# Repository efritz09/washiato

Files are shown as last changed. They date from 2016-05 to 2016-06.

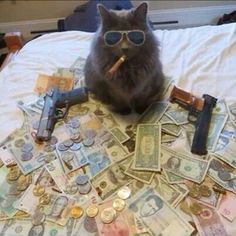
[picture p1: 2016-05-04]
Cat pictures/Thug_Kitty2.jpg

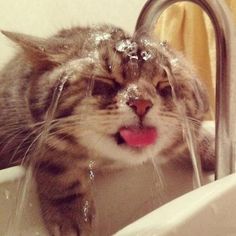
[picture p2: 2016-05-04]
Cat pictures/Idiot_Cat.jpg

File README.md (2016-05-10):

# washiato
ME 202 project

- Arya Banait
- Denny Delp
- Eric Fritz
- Tom the Tank Engine

=================
Have you ever started your laundry only to remember hours later that you never moved it over to the dryer?

Have you ever gone to pick up your laundry and some jerk has already moved it?

Enter **washiato**, a disruptive cloud based laundry monitoring system that will revolutionize the way you experience laundry!

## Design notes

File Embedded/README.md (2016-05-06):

# washiato
ME 202 project

### Installing the wifi board
To upload code to the huzzah board, follow the instructions here: [https://github.com/esp8266/Arduino](https://github.com/esp8266/Arduino)

#### Notes:
We're currently using a rolling mean and standard deviation to determine movement, using the algorithm defined here: [http://jonisalonen.com/2014/efficient-and-accurate-rolling-standard-deviation/](http://jonisalonen.com/2014/efficient-and-accurate-rolling-standard-deviation/)

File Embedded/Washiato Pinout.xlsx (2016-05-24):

Washiato Pinout
HUZZAH Pin | Connected To
0 | LCD RS
2 | LCD E
4 | Accelerometer SDA
5 | Accelerometer SCL
12 | LCD D4
13 | LCD D5
14 | LCD D6
15 | 2N7000 Gate
16 | LCD D7
3V | Accelerometer 3.3V
VBAT | 5 V supply
LCD Pin | Connected To
VSS | GND
VDD | 5V
V0 | Pot wiper
RS | Huzzah 0
RW | GND
E | HUZZAH 2
D0
D1
D2
D3
D4 | HUZZAH 12
D5 | HUZZAH 13
D6 | HUZZAH 14
D7 | HUZZAH 16
A | 5V
K | 2N7000 Drain

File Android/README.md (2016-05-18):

# washiato
ME 202 project

### Ideas for libraries
Since Adriano says we need to use 2 more libraries, here's a short list of some that I think we could use:

[Leak Canary](https://github.com/square/leakcanary): Detects memory leaks and stops them.

[Calligraphy](https://github.com/chrisjenx/Calligraphy): Custom fonts.

Otherwise, check out [this](https://github.com/codepath/android_guides/wiki/Must-Have-Libraries) for more libraries. There's a huge list that's split up into categories at the bottom.

=================================================================================================
### 05/17/2016- Arya
Current status: Major OMW and logout bugs are fixed. Guest logout fixed. 

Everything operates under the assumption that the user does not log out during a washing cycle. 
If they do so, we "lose" the pairing with NFC serial (its exists in Firebase, but is not displayed if they log back in). 
This is a small enough bug and I think we are okay for checkoff; but we should try to fix it for later!

Next Steps: Fix this bug such that an NFC serial stays associated with a user until the cycle is finished for them 
(and also display that even if they log out and log back in during a cycle).

=================================================================================================
### 05/16/2016- Arya
Control Activity page displays current and default cluster for each user (so does FireBase). 
I was trying to get Cluster Activity to display different ListViews depending on 
current cluster. Code will compile, but functionality-wise is kinda buggy and not entirely working. 

Next Step: Make a user class to locally store changes to Firebase variables currCluster and DefaultCluster
and add listeners for these. Lack of this class is causing the bugs. Will fix tomorrow.

=================================================================================================
### 05/10/2016- Eric
The login appears to be finished. It has memory so we don't need to login every time. Guest login works. If we register a new person, the login screen autopopulates it with the new user's credentials. 

Also, for NFC permission, there's now a popup screen that lets you stop seeing the "turn on NFC" alert and a button on the control screen to take you to the NFC settings to turn it on. 

I made some Shared Preferences variables global to the app so anything that needs to be stored there can use what I've set up. Right now it just stores the login status and the NFC nagging preference

=================================================================================================

### 05/09/2016- Arya
This one reads NFC tags and displays serial number of each tag in Control Activity; also pushes the serial number to Firebase (another child under user uid). FYI, if you try a different NFC tag after, it updates the serial number in Firebase and on screen.

Files changed: ControlActivity.java, AndroidManifest.xml, content_control.xml

Working on how to destroy the serial number data after a washing cycle is complete (because if another user uses it afterward, the old user might still keep seeing time remaining, etc?).

=================================================================================================

### 05/06/2016- Arya
This is a basic barebones app template copied off of my smart bike code. Develop further! What it does:

-Compiles and runs (LOL)

-Registers a user with Firebase

-Allows you to login via Firebase

-Shows a silly laundry meme when you login. I'll play with it more to make it better, but this is what I currently have.

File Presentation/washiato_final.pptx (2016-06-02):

## washiato

…..because Laundry matters!

Arya Banait
Denny Delp
Eric Fritz
Tom Owlett

## Shared Laundry Is a Mess

- Impossible to check idle machines
- No reminders to move clothing
- Laundry gets moved soon after cycle completes

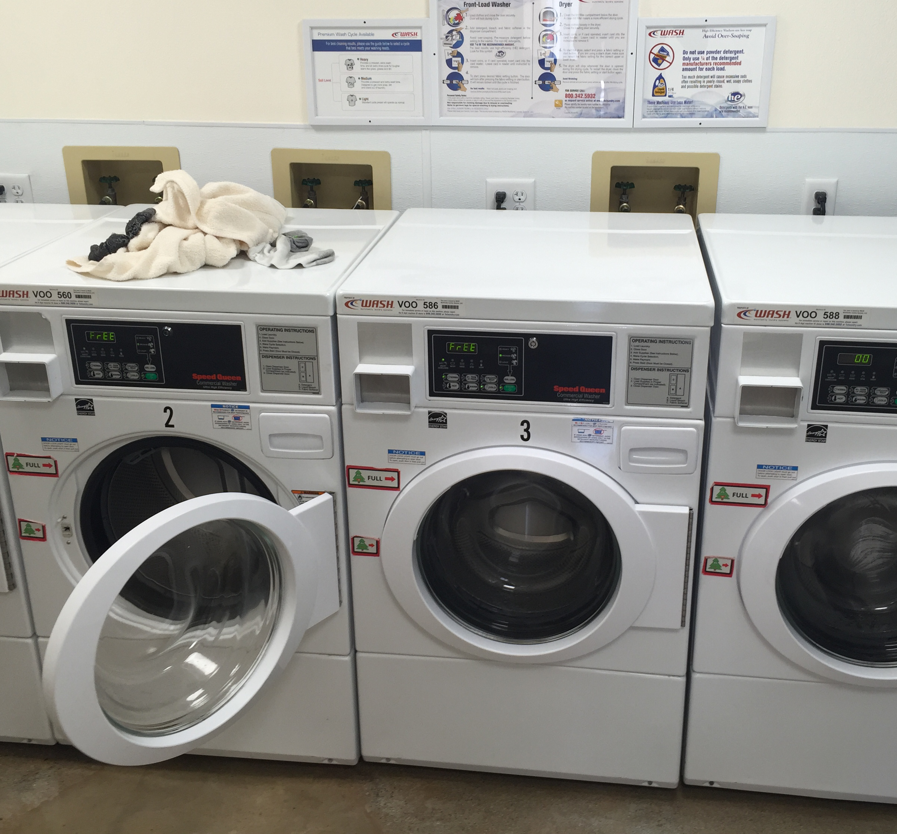
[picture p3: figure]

## Washiato Demo

## Coin Laundry is a Big Business

- There are 35,000 coin-operated laundries serving an estimated 100 million Americans
- These laundromats pull in $5B a year in gross revenue
- Come up with some bullshit sales stuff

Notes: These numbers include both coin laundromats and coin operated laundry machines in buildings

## Sales

- Target college campuses and apartment buildings
  - Improve laundry room efficiency and provide analytics to the building owners
  - Provide value for building residents.
- Retrofit means that apartments can provide this amenity for a much lower cost than replacing machines

## Team

- We’re all Stanford mechatronics wizards
- If you guys knew half the shit that we know, your fuzzy little heads would explode

## Go to Market

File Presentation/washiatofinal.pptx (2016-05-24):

## washiato

…..because Laundry matters!

Bitches be trippin
Thursday, 26th May 2016

Arya Banait
Denny Delp
Eric Fritz
Tom Owlett

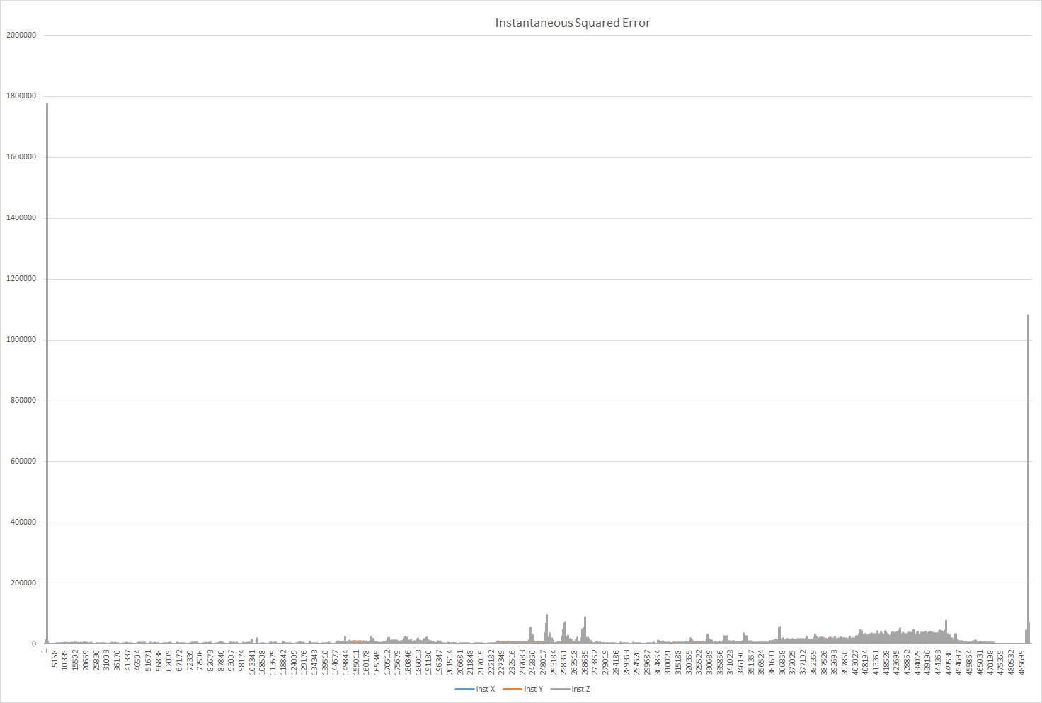
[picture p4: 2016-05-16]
Embedded/Washing Cycle Data/Inst_z.png

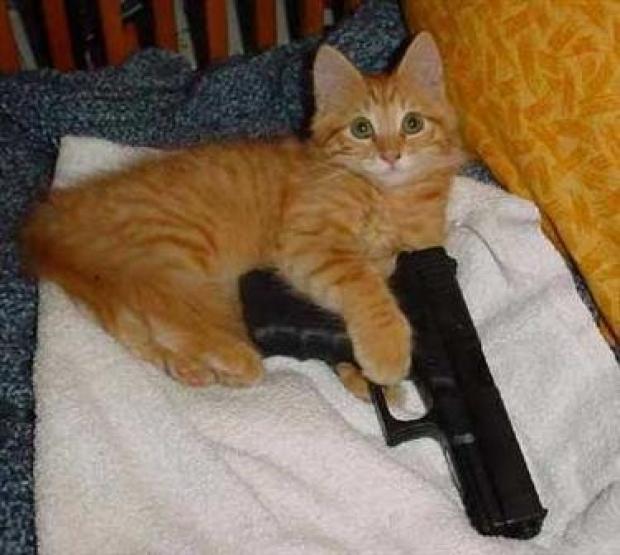
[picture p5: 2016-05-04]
Cat pictures/Thug_Kitty.jpg

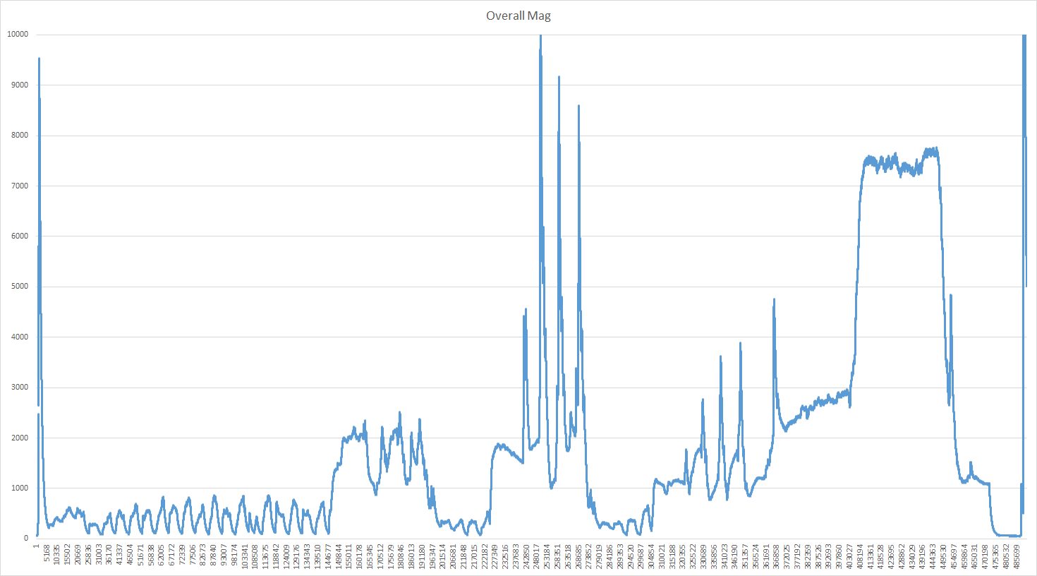
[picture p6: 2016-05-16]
Embedded/Washing Cycle Data/Acc_Mag.png

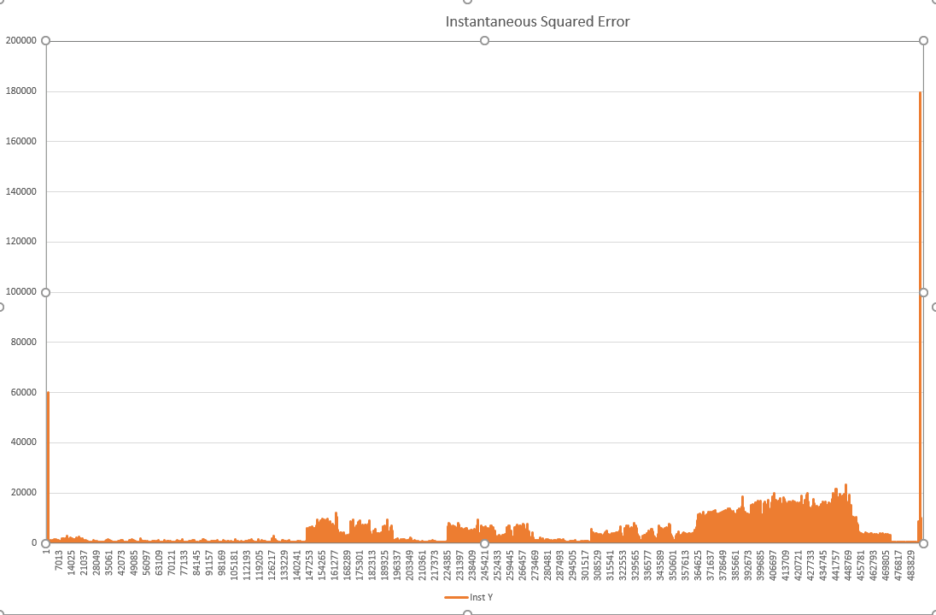
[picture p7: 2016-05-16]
Embedded/Washing Cycle Data/Inst_y.png

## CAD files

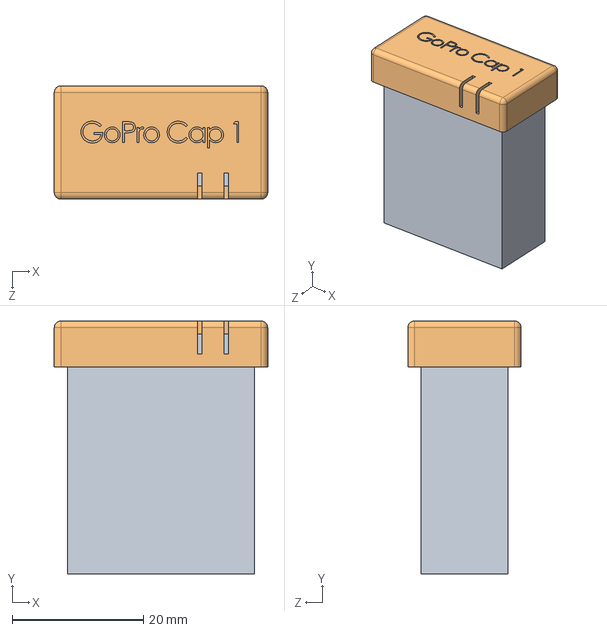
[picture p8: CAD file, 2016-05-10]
Mechanical Design/COMMUNAL_PARTS/BATTERY_CAP_ASSEMBLY.SLDASM
32.5 x 38.5 x 17.2 mm
GOPRO_BATTERY
GOPRO_BATTERY_MOUNT

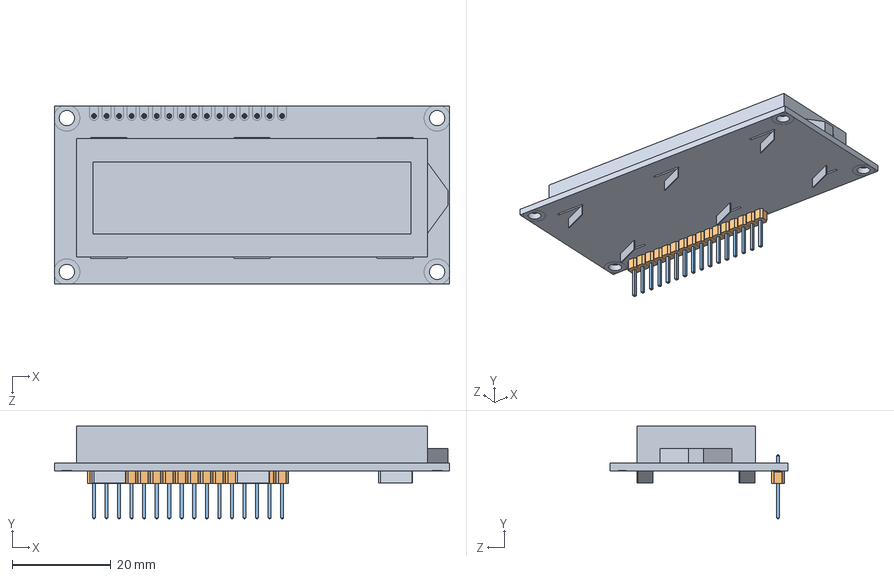
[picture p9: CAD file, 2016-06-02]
Deliverables/CAD/LCD.SLDASM
80.0 x 18.8 x 36.0 mm
LCD_BOARD
PIN_HEADER x 16
PIN x 16

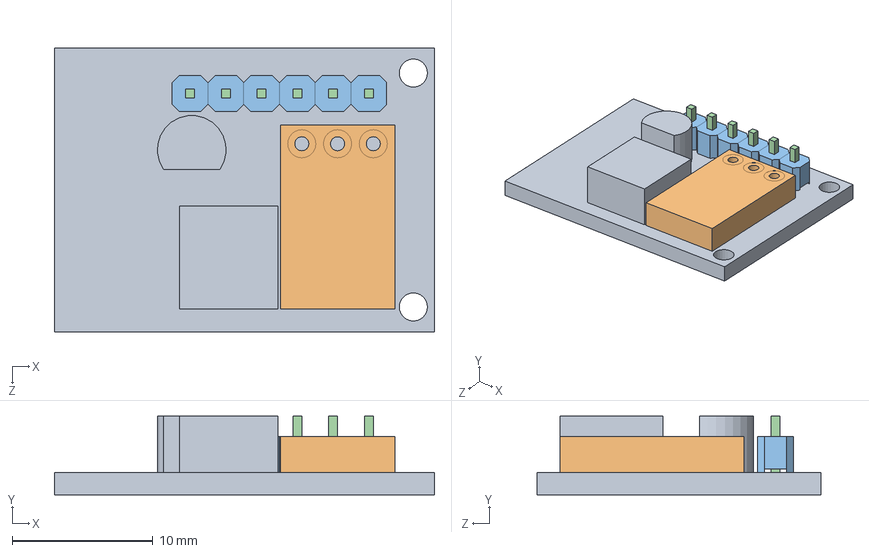
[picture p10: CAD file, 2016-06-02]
Deliverables/CAD/PROTOBOARD_ASSEM.SLDASM
27.0 x 5.60 x 20.2 mm
PROTOBOARD_SMALL
POLOLU_U3V12F5
PIN_HEADER x 6
PIN x 6

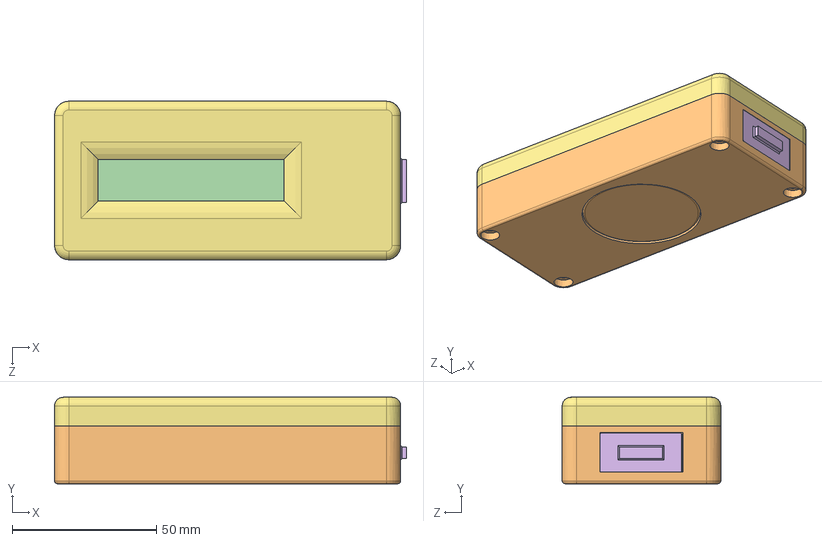
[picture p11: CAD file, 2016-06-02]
Deliverables/CAD/WASHIATO_1_0.SLDASM
122.0 x 30.0 x 55.0 mm
GOPRO_BATTERY
MAGNET
NFC_TAG
LCD_BOARD
PIN_HEADER x 28
PIN x 28
TOP
WIFI_HUZZAH
SPARKFUN_MMA8452Q_BOARD
BASE
PROTOBOARD_SMALL
POLOLU_U3V12F5
SWITCH
BATTERY_COVER

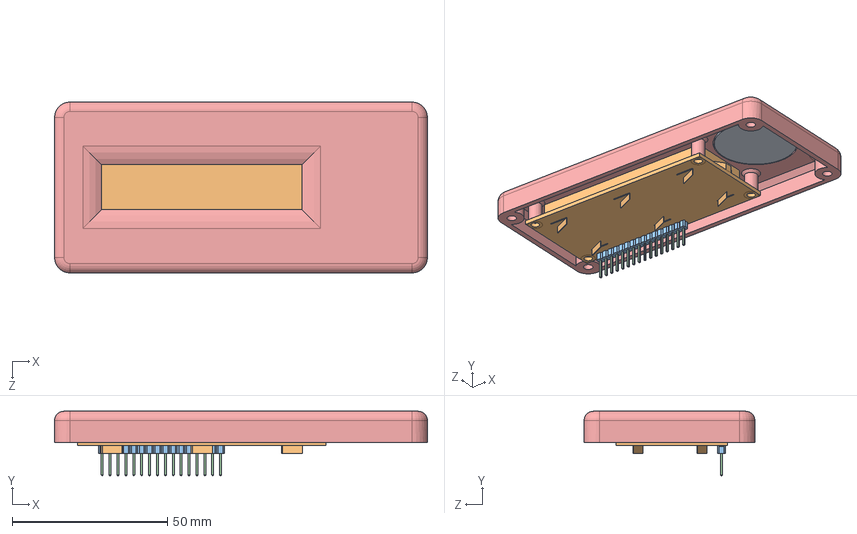
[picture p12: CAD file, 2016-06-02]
Deliverables/CAD/UpperAssem.sldasm
120.0 x 20.8 x 55.0 mm
NFC_TAG
LCD_BOARD
PIN_HEADER x 16
PIN x 16
TOP

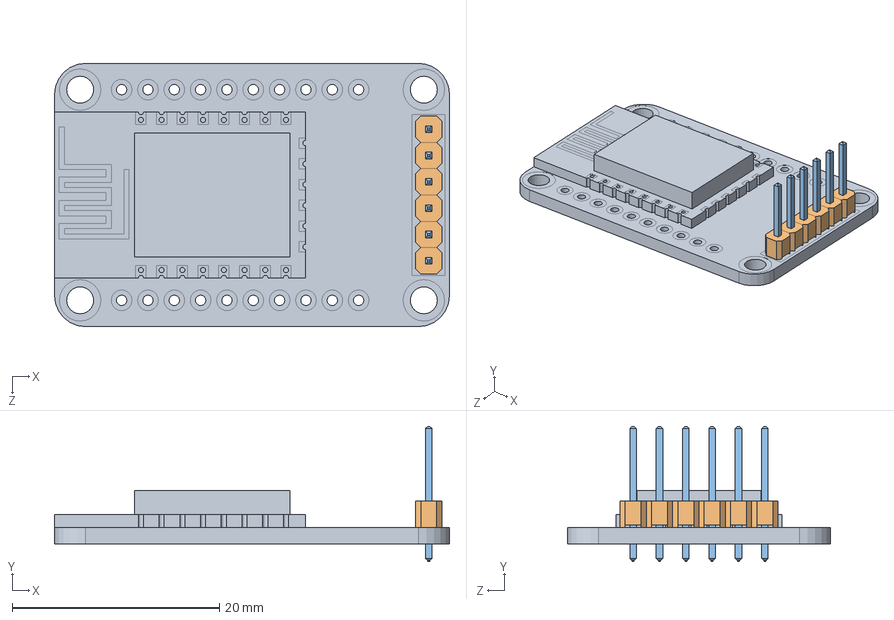
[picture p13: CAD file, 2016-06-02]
Deliverables/CAD/WIFI_CHIP.SLDASM
38.1 x 13.0 x 25.4 mm
WIFI_HUZZAH
PIN_HEADER x 6
PIN x 6

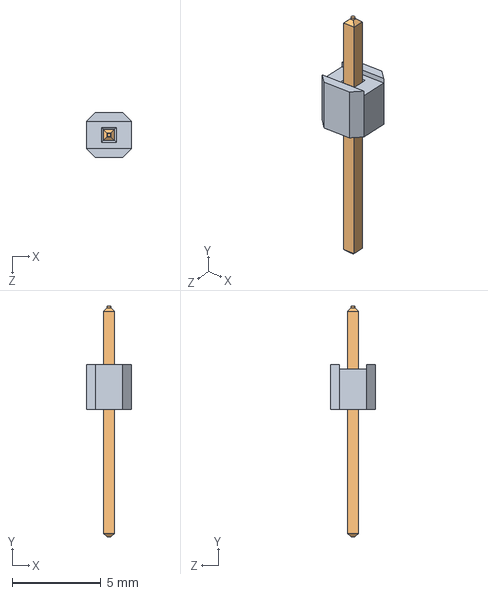
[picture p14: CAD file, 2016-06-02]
Deliverables/CAD/SIP_HEADER.SLDASM
2.54 x 13.0 x 2.54 mm
PIN_HEADER
PIN

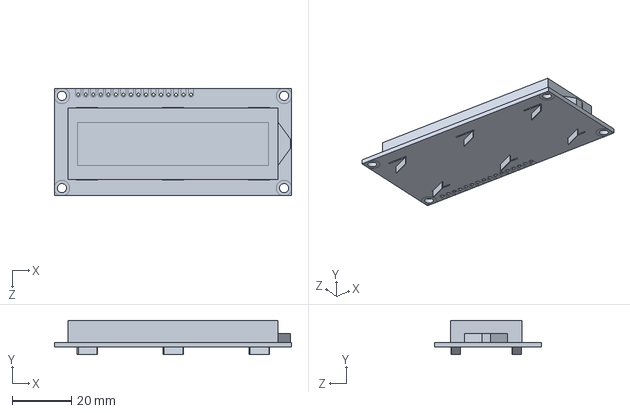
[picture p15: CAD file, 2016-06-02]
Deliverables/CAD/LCD_BOARD.SLDPRT
80.0 x 11.6 x 36.0 mm

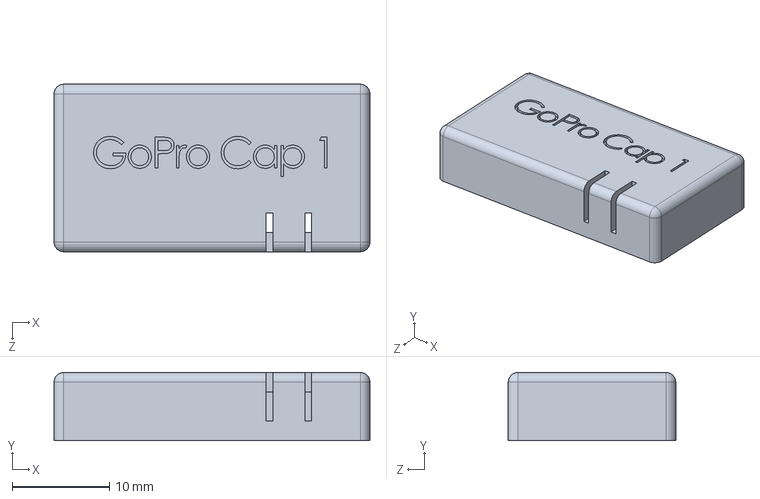
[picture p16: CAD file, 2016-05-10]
Mechanical Design/COMMUNAL_PARTS/GOPRO_BATTERY_MOUNT.SLDPRT
32.5 x 7.00 x 17.2 mm

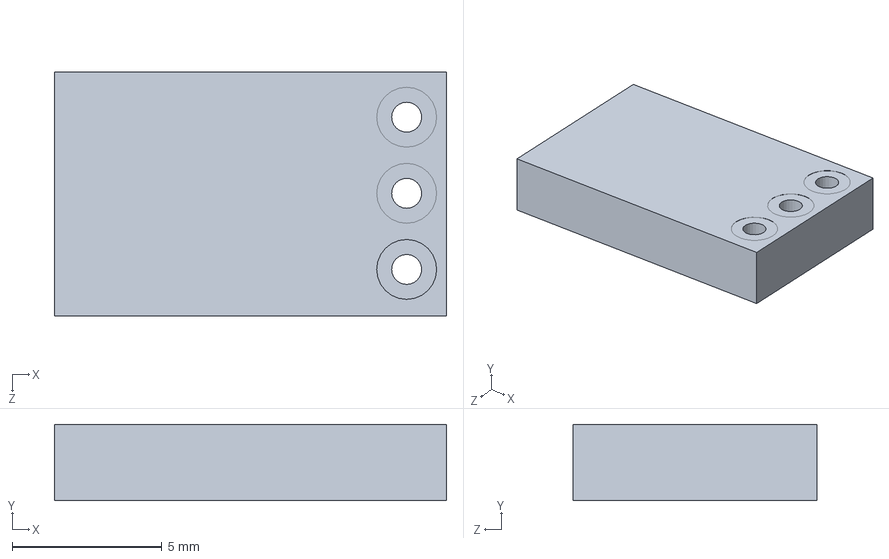
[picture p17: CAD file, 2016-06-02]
Deliverables/CAD/POLOLU_U3V12F5.SLDPRT
13.1 x 2.54 x 8.13 mm

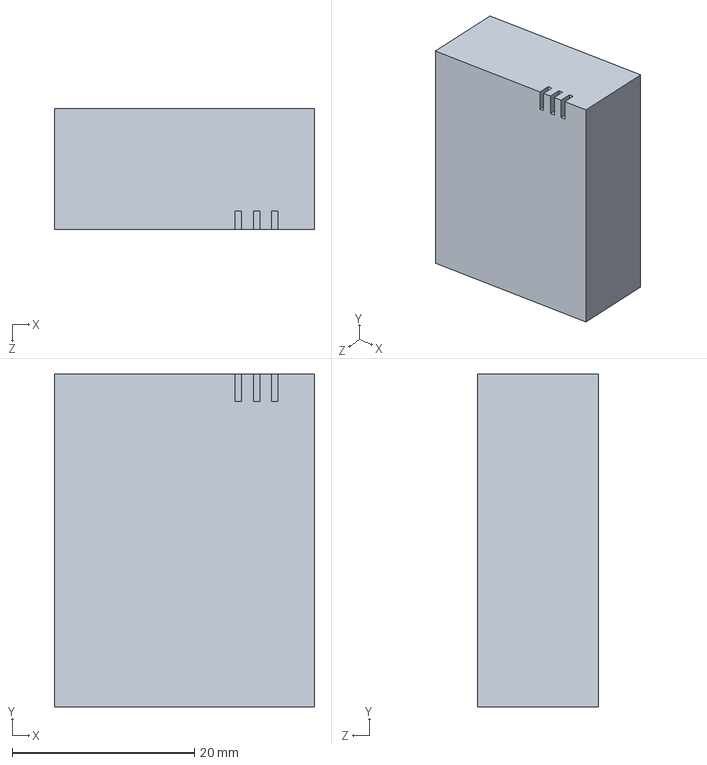
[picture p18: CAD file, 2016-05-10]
Mechanical Design/COMMUNAL_PARTS/GOPRO_BATTERY.SLDPRT
28.5 x 36.5 x 13.2 mm

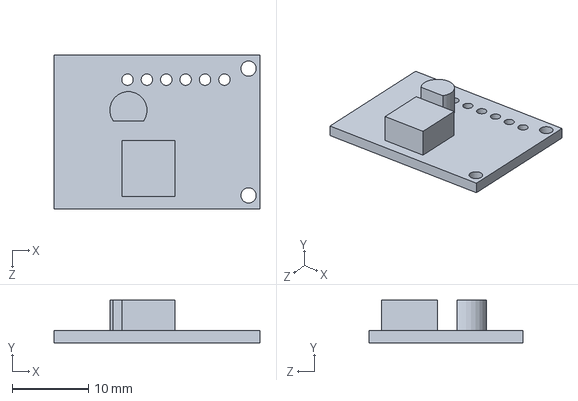
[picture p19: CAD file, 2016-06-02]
Deliverables/CAD/PROTOBOARD_SMALL.SLDPRT
27.0 x 5.60 x 20.2 mm

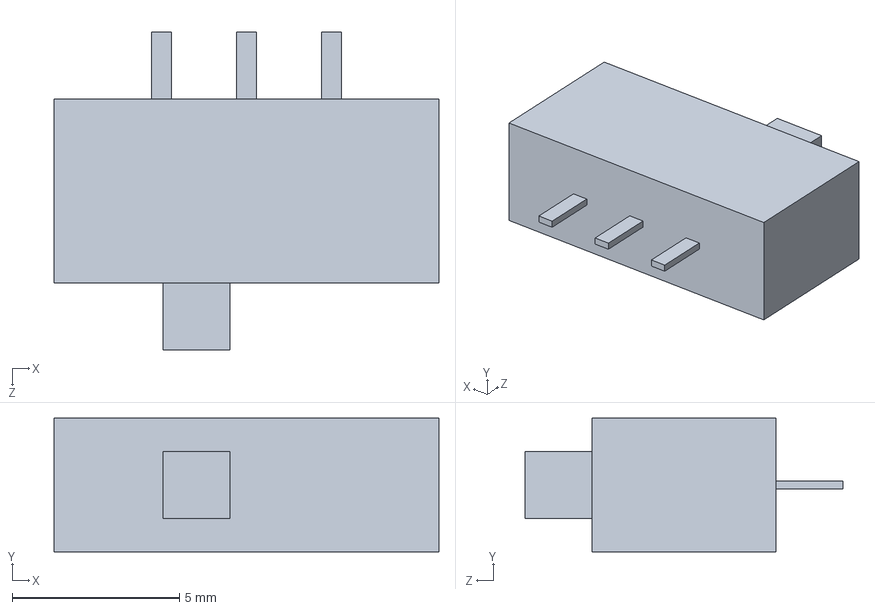
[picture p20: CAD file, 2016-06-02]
Deliverables/CAD/SWITCH.SLDPRT
11.5 x 4.00 x 9.50 mm

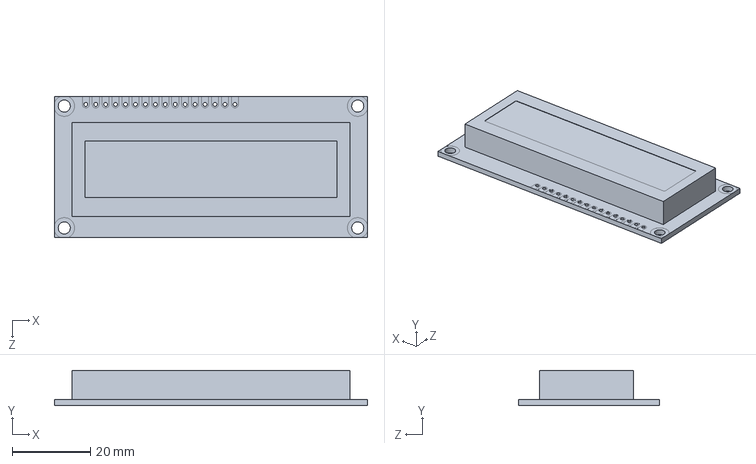
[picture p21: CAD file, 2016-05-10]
Mechanical Design/COMMUNAL_PARTS/LCD_BOARD.SLDPRT
80.0 x 9.05 x 36.0 mm

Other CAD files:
Deliverables/CAD/Assem3.sldasm
Mechanical Design/ForPrinting/5_10_GoProMount/GOPRO_BATTERY_MOUNT_1_0.STL
Deliverables/CAD/GOPRO_BATTERY.SLDPRT
Mechanical Design/COMMUNAL_PARTS/WIFI_HUZZAH.SLDPRT
Deliverables/CAD/BASE.SLDPRT
Deliverables/CAD/BATTERY_COVER.SLDPRT
Deliverables/CAD/MAGNET.SLDPRT
Deliverables/CAD/NFC_TAG.SLDPRT
Deliverables/CAD/PIN.SLDPRT
Deliverables/CAD/PIN_HEADER.SLDPRT
Deliverables/CAD/SPARKFUN_MMA8452Q_BOARD.SLDPRT
Deliverables/CAD/TOP.SLDPRT
Deliverables/CAD/WIFI_HUZZAH.SLDPRT
Mechanical Design/COMMUNAL_PARTS/LIMIT_SWITCH.SLDPRT
Mechanical Design/COMMUNAL_PARTS/POLOLU_U3V12F5.SLDPRT

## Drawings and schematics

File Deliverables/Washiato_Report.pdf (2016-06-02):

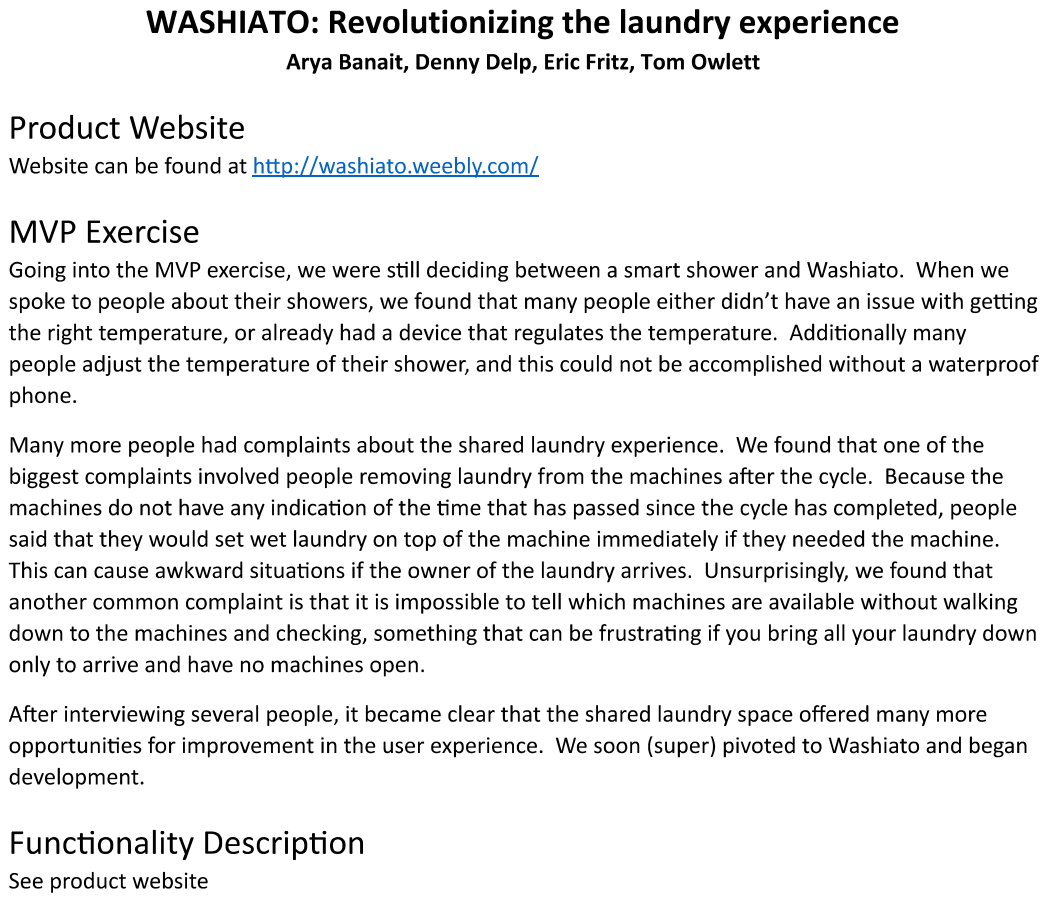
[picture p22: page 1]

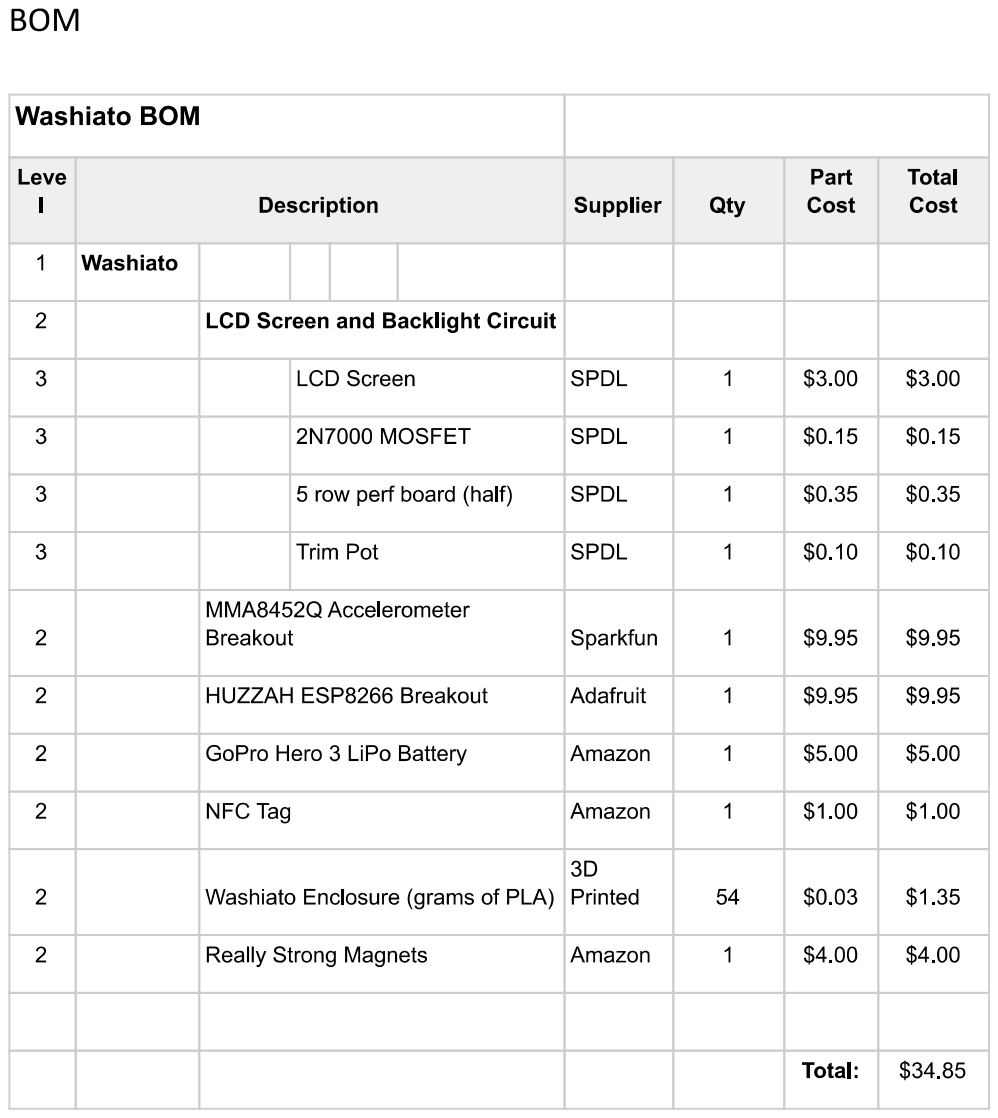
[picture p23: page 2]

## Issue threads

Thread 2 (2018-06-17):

No need to wait after Wire.requestFrom().

Koepel, 2018-06-17:
In all four "ESP8266_MMA8452Q.cpp" files you may remove the "`while(!Wire.available()) ;`" and "`while(Wire.available() < len);`" after the Wire.requestFrom().
Explanation: [Common-mistakes#1](https://github.com/Koepel/How-to-use-the-Arduino-Wire-library/wiki/Common-mistakes#1)

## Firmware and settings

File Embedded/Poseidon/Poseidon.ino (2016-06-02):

/*
 *  Washiato first pass
 */

#include <ESP8266WiFi.h>
#include <FirebaseArduino.h>
#include "ESP8266_MMA8452Q.h"
#include <Arduino.h>
#include <LiquidCrystal.h>

#define BACKLIGHT_PIN 15

// Machine States
#define MACHINE_UNOCCUPIED 0
#define MACHINE_WASHING 2
#define MACHINE_FINISHED 1

// Some Constants
#define Window_Samples 250
#define UPPER_ACCEL_THRESHOLD 2000
#define LOWER_ACCEL_THRESHOLD 1500
#define DOOR_THRESHOLD 50000
#define RMS_CAP 10000
#define ONE_MIN 60000


// NEED TO BE CHANGED FOR INDIVIDUAL DEVICES!!!
String NFC_ID = "04282352783F81";
//const char* ssid = "Stanford Residences";

const char* ssid = "washiato";
//const char* pwd = "washiato";

// Module level variables
static String MAC_address = "";
static int MachineState = MACHINE_UNOCCUPIED;
static unsigned long lastEvent;
static unsigned long lastOMWTime;
static unsigned long lastCompleteTime;
static bool isMoving;
static bool door_close;
static bool lastOMWStatus;
MMA8452Q accel;
LiquidCrystal lcd(0, 2, 12, 13, 14, 16);

// Initialization function
void setup() {
  Serial.begin(115200);
  delay(100);
  Serial.println("");
  Serial.print("Attempting to connect to ");
  Serial.println(ssid);

  //Set up GPIO
  pinMode(BACKLIGHT_PIN, OUTPUT);

  // set up the LCD's number of columns and rows:
  lcd.begin(16, 2);
  // Print a message to the LCD.
  lcd.print("Connecting to: ");
  lcd.setCursor(0,1);
  lcd.print(ssid);
  // Turn on backlight
  digitalWrite(BACKLIGHT_PIN, HIGH);
  
  //Connect to wifi
  //WiFi.begin(ssid, pwd);
  WiFi.begin(ssid);

  // Get MAC address for use as a unique ID
  byte MAC_array[6];
  WiFi.macAddress(MAC_array);
  for (int i=0; i < sizeof(MAC_array); ++i) {
    MAC_address = MAC_address + String(MAC_array[i], HEX);
  }

  Serial.print("Device MAC: ");
  Serial.println(MAC_address);

  // Wait until you are actually connected
  while (WiFi.status() != WL_CONNECTED) {
    delay(500);
    Serial.print(".");
  }
  
  // Print WiFi data for debugging
  Serial.println("");
  Serial.println("WiFi connected");  
  Serial.print("IP address: ");
  Serial.println(WiFi.localIP());

  //Set up firebase object
  Firebase.begin("washiato.firebaseIO.com", "N1tSzx0jsBjsBrbpnmHL8Gn3INnlwyrkbyMq110v");
  Serial.println("Firebase Successfully Initialized");

  // Set up accelerometer object
  lcd.clear();
  lcd.print("Init Accel");
  accel.init(SCALE_2G, ODR_800);
  Serial.println("Accelerometer Successfully Initialized");

  // Set FB and LCD statuses
  setFBStatus(MACHINE_UNOCCUPIED);
  setLCDStatus(MACHINE_UNOCCUPIED); 
}

// Main loop containing SM
void loop() {
  
 int NextMachineState = MachineState;
 // Update Acceleration values first
 checkMovement();

 // Machine State machine
 switch(MachineState) {
  
  case MACHINE_UNOCCUPIED:
    // If we have detected that it is moving, go to washing state
    if (isMoving) {
      Serial.println("Now Washing");
      NextMachineState = MACHINE_WASHING;
      setFBStatus(MACHINE_WASHING);
      setLCDStatus(MACHINE_WASHING);
      lastEvent = millis();
    }
    break;
  
  case MACHINE_WASHING:
    // If the machine is no longer moving, go to finished state
    if (!isMoving) {
      Serial.println("Now Finished");
      NextMachineState = MACHINE_FINISHED;
      setFBStatus(MACHINE_FINISHED);
      setLCDStatus(MACHINE_FINISHED);
      lastEvent = millis();
      lastCompleteTime = millis();
      setFBTime(0);
      resetOMWStatus();
    }
    break;
    
  case MACHINE_FINISHED:
      // If a door close has been detected, go to unoccupied state
      if (door_close) {
        Serial.println("Now Unoccupied");
        NextMachineState = MACHINE_UNOCCUPIED;
        setFBStatus(MACHINE_UNOCCUPIED);
        setLCDStatus(MACHINE_UNOCCUPIED);
        resetOMWStatus();
        lastEvent = millis();
        lastOMWStatus = false;
        setFBTime(0);
      }

     // If more than a second has passed since we checked if someone is on the way
     if (millis() - lastOMWTime > 1000) {
      // Check if someone is on the way
      if (checkOMWStatus() && lastOMWStatus == false) {
        lcd.clear();
        lcd.print("I'm on my way!");
        lastEvent = millis();
        lastOMWStatus = true;
      }
      lastOMWTime = millis();
     }

     // If we have recently rolled over a minute, update firebase
     if (((millis()-lastCompleteTime)%60000) < 20) {
      setFBTime((uint16_t)((millis()-lastCompleteTime)/60000));
      Serial.println("Setting FB Time");
     }
    break;
 }
 
 // Set the time line on the LCD
 setLCDTime();
 MachineState = NextMachineState;
}

// Function to calculate moving average/variance and return bool to indicate whether washer is on
// Using algorithms from here: http://jonisalonen.com/2014/efficient-and-accurate-rolling-standard-deviation/
void checkMovement(void) {
  // Initialize averages to current value so that we come out of reset with zero variance
  accel.read();
  static float x_mu = (float)accel.x;   // moving average of x acceleration
  static float x_s;                     // moving variance of x acceleration
  static float y_mu = (float)accel.y;   // moving average of y acceleration
  static float y_s;                     // moving variance of y acceleration
  static float z_mu = (float)accel.z;   // moving average of z acceleration
  static float z_s;                     // moving variance of z acceleration

  static float Accel_Var_Threshold = UPPER_ACCEL_THRESHOLD;

  // Update variances if new accelerometer values are available
  if (accel.available()) {
    accel.read();
    float new_x = (float)accel.x;
    float new_y = (float)accel.y;
    float new_z = (float)accel.z;
    // Calculate x stuff
    x_mu = x_mu - (x_mu/Window_Samples) + (new_x/Window_Samples);
    float x_diff = sq(new_x-x_mu);
    
    // Calculate y stuff
    y_mu = y_mu - (y_mu/Window_Samples) + (new_y/Window_Samples);
    float y_diff = sq(new_y-y_mu);
    
    // Calculate z stuff
    z_mu = z_mu - (z_mu/Window_Samples) + (new_z/Window_Samples);
    float z_diff = sq(new_z-z_mu);

    // Check door slam
    door_close = (sqrt(sq(x_diff)+sq(y_diff)+sq(z_diff)) > DOOR_THRESHOLD); 

    // Implement cap to lessen impact of short impacts
    if (x_diff > RMS_CAP) {
      x_diff = RMS_CAP;
    }

    if (y_diff > RMS_CAP) {
      y_diff = RMS_CAP;
    }

    if (z_diff > RMS_CAP) {
      z_diff = RMS_CAP;
    }
    
    // if value wasn't from door, add it to new magnitude
    if (!door_close) {
      x_s = x_s - (x_s/(Window_Samples)) + (x_diff/(Window_Samples));
      y_s = y_s - (y_s/(Window_Samples)) + (y_diff/(Window_Samples));
      z_s = z_s - (z_s/(Window_Samples)) + (z_diff/(Window_Samples));
    }

    Serial.println(sqrt(sq(x_s)+sq(y_s)+sq(z_s)));
    
  }

  // decide whether we are moving
  isMoving = (sqrt(sq(x_s)+sq(y_s)+sq(z_s)) > Accel_Var_Threshold);

  // Introduce software hysteresis so we don't flip back and forth
  if (isMoving) {
    Accel_Var_Threshold = LOWER_ACCEL_THRESHOLD;
  } else {
    Accel_Var_Threshold = UPPER_ACCEL_THRESHOLD;
  }
  
  return;
}

// Function to set the status of the washing machine in FB
void setFBStatus(int newStatus) {
  Firebase.set("Machines/" + NFC_ID + "/status", newStatus);
}

// Function to set the time on the lcd panel since the "last event" variable has been updated
void setLCDTime(void) {
  lcd.setCursor(0,1);
  unsigned long timeDiff = millis()-lastEvent;
  if (timeDiff<ONE_MIN) {
    lcd.print((String)(timeDiff/1000) + " sec ago");
  } else {
    lcd.print((String)(timeDiff/60000) + " m " + (String)((timeDiff%60000)/1000) + " s ago ");
  }
}

// Function to clear the LCD screen and set the status line of the LCD display
void setLCDStatus(int newStatus) {
  switch (newStatus) {
    case MACHINE_UNOCCUPIED:
      lcd.clear();
      lcd.setCursor(0,0);
      lcd.print("Machine unloaded");
      break;
    case MACHINE_WASHING:
      lcd.clear();
      lcd.setCursor(0,0);
      lcd.print("Machine started");
      break;
    case MACHINE_FINISHED:
      lcd.clear();
      lcd.setCursor(0,0);
      lcd.print("Machine finished");
    break;
  }
}

// Function to reset the on my way status for the machine in Firebase
void resetOMWStatus(void) {
  Firebase.set("Machines/" + NFC_ID + "/omw", false);
}

// Returns true if the clothing owner has responded in the app
bool checkOMWStatus(void) {
  return (bool)Firebase.get(("Machines/" + NFC_ID + "/omw").c_str());
}

// Takes a time in minutes since the last cycle completed and posts it to firebase
void setFBTime(uint16_t newMins) {
  Firebase.set("Machines/" + NFC_ID + "/time", newMins);
}

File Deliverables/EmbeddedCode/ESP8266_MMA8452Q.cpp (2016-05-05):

/******************************************************************************
SFE_MMA8452Q.cpp
SFE_MMA8452Q Library Source File
Jim Lindblom @ SparkFun Electronics
Original Creation Date: June 3, 2014
https://github.com/sparkfun/MMA8452_Accelerometer

This file implements all functions of the MMA8452Q class. Functions here range
from higher level stuff, like reading/writing MMA8452Q registers to low-level,
hardware I2C reads and writes.

Development environment specifics:
	IDE: Arduino 1.0.5
	Hardware Platform: Arduino Uno

This code is beerware; if you see me (or any other SparkFun employee) at the
local, and you've found our code helpful, please buy us a round!

Distributed as-is; no warranty is given.
******************************************************************************/

#include "ESP8266_MMA8452Q.h"
#include <Arduino.h>
#include <Wire.h>

// CONSTRUCTUR
//   This function, called when you initialize the class will simply write the
//   supplied address into a private variable for future use.
//   The variable addr should be either 0x1C or 0x1D, depending on which voltage
//   the SA0 pin is tied to (GND or 3.3V respectively).
MMA8452Q::MMA8452Q(byte addr)
{
	address = addr; // Store address into private variable
}

// INITIALIZATION
//	This function initializes the MMA8452Q. It sets up the scale (either 2, 4,
//	or 8g), output data rate, portrait/landscape detection and tap detection.
//	It also checks the WHO_AM_I register to make sure we can communicate with
//	the sensor. Returns a 0 if communication failed, 1 if successful.
byte MMA8452Q::init(MMA8452Q_Scale fsr, MMA8452Q_ODR odr)
{
	scale = fsr; // Haul fsr into our class variable, scale
	
	Wire.begin(); // Initialize I2C
	
	byte c = readRegister(WHO_AM_I);  // Read WHO_AM_I register
	
	if (c != 0x2A) // WHO_AM_I should always be 0x2A
	{
		return 0;
	}
	
	standby();  // Must be in standby to change registers
	
	setScale(scale);  // Set up accelerometer scale
	setODR(odr);  // Set up output data rate
	setupPL();  // Set up portrait/landscape detection
	// Multiply parameter by 0.0625g to calculate threshold.
	setupTap(0x80, 0x80, 0x08); // Disable x, y, set z to 0.5g
	
	active();  // Set to active to start reading
	
	return 1;
}

// READ ACCELERATION DATA
//  This function will read the acceleration values from the MMA8452Q. After
//	reading, it will update two triplets of variables:
//		* int's x, y, and z will store the signed 12-bit values read out
//		  of the acceleromter.
//		* floats cx, cy, and cz will store the calculated acceleration from
//		  those 12-bit values. These variables are in units of g's.
void MMA8452Q::read()
{
	byte rawData[6];  // x/y/z accel register data stored here

	readRegisters(OUT_X_MSB, rawData, 6);  // Read the six raw data registers into data array
	
	x = (rawData[0]<<8 | rawData[1]) >> 4;
	y = (rawData[2]<<8 | rawData[3]) >> 4;
	z = (rawData[4]<<8 | rawData[5]) >> 4;
  x = (x >> 11) == 0 ? x : -1 ^ 0xFFF | x;
  y = (y >> 11) == 0 ? y : -1 ^ 0xFFF | y;
  z = (z >> 11) == 0 ? z : -1 ^ 0xFFF | z;
	cx = (float) x / (float)(1<<11) * (float)(scale);
	cy = (float) y / (float)(1<<11) * (float)(scale);
	cz = (float) z / (float)(1<<11) * (float)(scale);
}

// CHECK IF NEW DATA IS AVAILABLE
//	This function checks the status of the MMA8452Q to see if new data is availble.
//	returns 0 if no new data is present, or a 1 if new data is available.
byte MMA8452Q::available()
{
	return (readRegister(STATUS_M) & 0x08) >> 3;
}

// SET FULL-SCALE RANGE
//	This function sets the full-scale range of the x, y, and z axis accelerometers.
//	Possible values for the fsr variable are SCALE_2G, SCALE_4G, or SCALE_8G.
void MMA8452Q::setScale(MMA8452Q_Scale fsr)
{
	// Must be in standby mode to make changes!!!
	byte cfg = readRegister(XYZ_DATA_CFG);
	cfg &= 0xFC; // Mask out scale bits
	cfg |= (fsr >> 2);  // Neat trick, see page 22. 00 = 2G, 01 = 4A, 10 = 8G
	writeRegister(XYZ_DATA_CFG, cfg);
}

// SET THE OUTPUT DATA RATE
//	This function sets the output data rate of the MMA8452Q.
//	Possible values for the odr parameter are: ODR_800, ODR_400, ODR_200, 
//	ODR_100, ODR_50, ODR_12, ODR_6, or ODR_1
void MMA8452Q::setODR(MMA8452Q_ODR odr)
{
	// Must be in standby mode to make changes!!!
	byte ctrl = readRegister(CTRL_REG1);
	ctrl &= 0xCF; // Mask out data rate bits
	ctrl |= (odr << 3);
	writeRegister(CTRL_REG1, ctrl);
}

// SET UP TAP DETECTION
//	This function can set up tap detection on the x, y, and/or z axes.
//	The xThs, yThs, and zThs parameters serve two functions:
//		1. Enable tap detection on an axis. If the 7th bit is SET (0x80)
//			tap detection on that axis will be DISABLED.
//		2. Set tap g's threshold. The lower 7 bits will set the tap threshold
//			on that axis.
void MMA8452Q::setupTap(byte xThs, byte yThs, byte zThs)
{
	// Set up single and double tap - 5 steps:
	// for more info check out this app note:
	// http://cache.freescale.com/files/sensors/doc/app_note/AN4072.pdf
	// Set the threshold - minimum required acceleration to cause a tap.
	byte temp = 0;
	if (!(xThs & 0x80)) // If top bit ISN'T set
	{
		temp |= 0x3; // Enable taps on x
		writeRegister(PULSE_THSX, xThs);  // x thresh
	}
	if (!(yThs & 0x80))
	{
		temp |= 0xC; // Enable taps on y
		writeRegister(PULSE_THSY, yThs);  // y thresh
	}
	if (!(zThs & 0x80))
	{
		temp |= 0x30; // Enable taps on z
		writeRegister(PULSE_THSZ, zThs);  // z thresh
	}
	// Set up single and/or double tap detection on each axis individually.
	writeRegister(PULSE_CFG, temp | 0x40);
	// Set the time limit - the maximum time that a tap can be above the thresh
	writeRegister(PULSE_TMLT, 0x30);  // 30ms time limit at 800Hz odr
	// Set the pulse latency - the minimum required time between pulses
	writeRegister(PULSE_LTCY, 0xA0);  // 200ms (at 800Hz odr) between taps min
	// Set the second pulse window - maximum allowed time between end of
	//	latency and start of second pulse
	writeRegister(PULSE_WIND, 0xFF);  // 5. 318ms (max value) between taps max
}

// READ TAP STATUS
//	This function returns any taps read by the MMA8452Q. If the function 
//	returns no new taps were detected. Otherwise the function will return the
//	lower 7 bits of the PULSE_SRC register.
byte MMA8452Q::readTap()
{
	byte tapStat = readRegister(PULSE_SRC);
	if (tapStat & 0x80) // Read EA bit to check if a interrupt was generated
	{
		return tapStat & 0x7F;
	}
	else
		return 0;
}

// SET UP PORTRAIT/LANDSCAPE DETECTION
//	This function sets up portrait and landscape detection.
void MMA8452Q::setupPL()
{
	// Must be in standby mode to make changes!!!
	// For more info check out this app note:
	//	http://cache.freescale.com/files/sensors/doc/app_note/AN4068.pdf
	// 1. Enable P/L
	writeRegister(PL_CFG, readRegister(PL_CFG) | 0x40); // Set PL_EN (enable)
	// 2. Set the debounce rate
	writeRegister(PL_COUNT, 0x50);  // Debounce counter at 100ms (at 800 hz)
}
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

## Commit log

2016-05-05 First pass at getting accelerometer working
2016-05-06 Added variance based accelerometer code to decide whether we're moving
2016-05-10 CAD folder added
    Communal parts for now
2016-05-10 Communal Parts folder added
    Off the shelf parts
    [GOPRO_BATTERY.SLDPRT, LCD_BOARD.SLDPRT, LIMIT_SWITCH.SLDPRT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]
2016-05-10 GoPro STL to print
    in mechanical/forprinting/(date)
    [BATTERY_CAP_ASSEMBLY.SLDASM, GOPRO_BATTERY.SLDPRT, GOPRO_BATTERY_MOUNT.SLDPRT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]
2016-05-12 Embedded code used to gather data for a full washing cycle.
    Code has serial prints to print out data values to the screen. First
    column is unfiltered square of difference of x acceleration, second
    column is unfiltered square of difference of y acceleration, third
    column is unfiltered square of difference of z acceleration, and final
    col is the magnitude of the three with a software lowpass.
2016-05-16 Framework for getting machine stuff into listview
    Uses a listview for now. I think a gridview would be better in the
    future.
2016-05-16 Added LCD display
    Testing an LCD display on the embedded side. Moved limit switch to pin
    15 so that appropriate pins can be pulled high/low on boot. LCD display
    is working. Also added excel analysis from washing cycle
2016-05-16 Last tested code with limit switch and LCD
    Currently moving to a smarter accelerometer system without a limit
    switch that can detect door activity.
2016-05-17 Tested default and current cluster status, both on screen and Firebase: Working
2016-05-18 App no longer crashes on devices without NFC support
2016-05-21 Code updated for snappier demo performance
    Thresholds adjusted based on experimental testing with mini washing
    machine.
    [Washiato Pinout.xlsx]
2016-05-23 Tab example added
    Added tabbed activity with two fragments (washer/dryer). Access through
    Tab button at bottom of control activity.
2016-05-24 UI update 4: Control Screen, minor features
    Flavortext, default cluster updates, conditionally invisible buttons
2016-05-25 Manual machine select, more machines in Olympus
    User can manually enter the name of the machine (Thor, Ares, etc, not
    case sensitive) to connect without NFC.
2016-05-25 Animation library added
    Also app doesn’t brute force it’s way open if you press the back button
    during the splash screen.
2016-05-26 preliminary tab merge
    framework working, no visuals
2016-06-02 CAD added to Deliverables
    [Assem3.sldasm, BASE.SLDPRT, BATTERY_COVER.SLDPRT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]
